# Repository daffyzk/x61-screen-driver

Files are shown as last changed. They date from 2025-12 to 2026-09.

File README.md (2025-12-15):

# x61-screen-driver

So far this is just collecting information...  

The idea is to eventually build a display driver pcb to make the screen output to HDMI/DP/eDP.  

Options for these screens on aliexpress/ebay are bulky and don't seem to be compatible with these screens either.

## Information:

There is an eDP/DP to LVDS integrated circuit from nxp, for around 5 bucks on some sites, model number PTN3460I.
the datasheet is in this repo.

There are some documents that specify some infomation on the display itself and how it comunicates

So far that's all I got, and some wikipedia articles:

[LVDS Standard](https://en.wikipedia.org/wiki/Low-voltage_differential_signaling)

## I/O 
for input, I couldn't find the original x61/x60 board-to-board connector anywhere, so I opted for this 40pin panasonic one:
https://www.digikey.com/en/products/detail/panasonic-electric-works/AXT640124/1986594
this does mean that it will required a special flex cable, but I am working on that too.

the output connector will be 20455-040E-76, standard 40pin eDP board-to-cable connector, used for displays like the BOE NE135FBM-N41
https://www.digikey.com/en/products/detail/i-pex/20455-040E-76/22108829

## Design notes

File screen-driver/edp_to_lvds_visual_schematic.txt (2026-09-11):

================================================================================
         eDP to LVDS CONVERTER - VISUAL SCHEMATIC DIAGRAM
         Framework 13 → PTN3460 → HV121P01-101 (1400x1050)
================================================================================

                         ┌─────────────────────────────────────────────────────────────────┐
                         │                                                                 │
    FRAMEWORK 13         │                      PTN3460IBS                                 │         HV121P01-101
    eDP OUTPUT           │                      (HVQFN56)                                  │         LVDS PANEL
                         │                                                                 │
  ┌──────────────┐       │  ┌─────────────────────────────────────────────────────────┐   │       ┌──────────────┐
  │              │       │  │                                                         │   │       │              │
  │  DP_LANE0_P  ├──C13──┼──┤ 4  DP0_P                                 LVSAO_P  53   ├───┼───────┤ RIN0+ (6)    │
  │  DP_LANE0_N  ├──C14──┼──┤ 5  DP0_N                                 LVSAO_N  54   ├───┼───────┤ RIN0- (5)    │
  │              │       │  │                                                         │   │       │              │
  │  DP_LANE1_P  ├──C15──┼──┤ 7  DP1_P                                 LVSBO_P  52   ├───┼───────┤ RIN1+ (9)    │
  │  DP_LANE1_N  ├──C16──┼──┤ 8  DP1_N                                 LVSBO_N  51   ├───┼───────┤ RIN1- (8)    │
  │              │       │  │                                                         │   │       │              │
  │  AUX_P       ├──C17──┼──┤ 2  AUX_P                                 LVSCO_P  48   ├───┼───────┤ RIN2+ (12)   │
  │  AUX_N       ├──C18──┼──┤ 1  AUX_N                                 LVSCO_N  49   ├───┼───────┤ RIN2- (11)   │
  │              │       │  │                                                         │   │       │              │
  │  HPD         ├───────┼──┤11  HPDRX                                LVSCKO_P  46   ├───┼───────┤ CLKIN+ (15)  │
  │              │       │  │                                         LVSCKO_N  47   ├───┼───────┤ CLKIN- (14)  │
  │              │       │  │                                                         │   │       │              │
  │  +3.3V       ├───────┼──┤    VDD3V3 (13,14,38,50)                    DDC_SCL 29   ├─┬─┼───────┤ EDID_CLK(19) │
  │  GND         ├───────┼──┤    GND (3,17,18,PAD)                       DDC_SDA 30   ├─┼─┼───────┤ EDID_DAT(20) │
  │              │       │  │                                                         │ │ │       │              │
  │  (Lane 2,3   │       │  │                                           PVCCEN  33   ├─┼─┼──NC   │ VDD (1,2)────┼──+3.3V
  │   unused)    │       │  │                                           BKLTEN  26   ├─┼─┼──────►│ LED_EN       │
  │              │       │  │                                             PWMO  28   ├─┼─┼──────►│ LED_PWM      │
  └──────────────┘       │  │                                                         │ │ │       │              │
                         │  │    CONFIG PINS:                                         │ │ │       │ GND(3,4,7,   │
       J1                │  │    ─────────────                                        │ │ │       │ 10,13,16,18) ├──GND
   40-pin eDP            │  │                                                         │ │ │       │              │
                         │  │    20 TESTMODE ◄────R5(10k)────GND                      │ │ │       └──────────────┘
                         │  │    21 CFG1 ◄────────────────────GND  (Single LVDS)      │ │ │             J2
                         │  │    22 CFG2 ◄────R6(10k)────VDD3V3    (18bpp)            │ │ │        20-pin LVDS
                         │  │    23 CFG3 ◄────────────────────GND  (2-lane eDP)       │ │ │
                         │  │    27 CFG4 ◄────R7(10k)────GND       (EDID emulation)   │ │ │
                         │  │                                                         │ │ │
                         │  │    CONTROL:                                             │ │ │
                         │  │    ────────                                             │ │ │
                         │  │     9 RST_N ◄────R8(10k)────VDD3V3                      │ │ │
                         │  │    10 PD_N  ◄────R9(10k)────VDD3V3                      │ │ │
                         │  │    56 EPS_N ◄────R10(10k)───VDD3V3   (Use int. 1.8V)    │ │ │
                         │  │    12 DEV_CFG ◄──R11(10k)───GND      (I2C addr 0x40)    │ │ │
                         │  │                                                         │ │ │
                         │  │    I2C PROGRAMMING:                                     │ │ │
                         │  │    ────────────────                                     │ │ │
                         │  │    24 MS_SDA ◄───R14(2.2k)──VDD3V3 ──────────┐          │ │ │
                         │  │    25 MS_SCL ◄───R13(2.2k)──VDD3V3 ────────┐ │          │ │ │
                         │  │                                            │ │          │ │ │
                         │  └────────────────────────────────────────────┼─┼──────────┘ │ │
                         │                                               │ │            │ │
                         └───────────────────────────────────────────────┼─┼────────────┘ │
                                                                         │ │              │
                                                                         │ │   I2C       │
                                 ┌───────────┐                           │ │  Pull-ups   │
                                 │ J3 (HDR)  │                           │ │      │      │
                                 │  1: VDD   ├───VDD3V3                  │ │      │      │
                                 │  2: SCL   ├───────────────────────────┘ │   R3(2.2k)  │
                                 │  3: SDA   ├─────────────────────────────┘      │      │
                                 │  4: GND   ├───GND                          VDD3V3    │
                                 └───────────┘                                          │
                                I2C Programming                                         │
                                    Header                                              │

================================================================================
                              POWER SUPPLY SECTION
================================================================================

                                           ┌────────────────────────────────────┐
        +3.3V_IN ──────┬───────────────────┤  VDD3V3 DISTRIBUTION               │
        (from eDP)     │                   │                                    │
                       │                   │  Pin 13 ──┬── C4(0.1µF) ── GND     │
                      C1                   │  Pin 14 ──┼── C5(0.1µF) ── GND     │
                     2.2µF                 │  Pin 38 ──┼── C6(0.1µF) ── GND     │
                       │                   │  Pin 50 ──┴── C7(0.1µF) ── GND     │
                      GND                  │                                    │
                                           └────────────────────────────────────┘

                                           ┌────────────────────────────────────┐
                                           │  1.8V REGULATOR OUTPUT (Pin 19)    │
                                           │                                    │
        Pin 19 (VDD1V8_REG) ───┬───────────┤  ──┬── C8(4.7µF) ── GND            │
                               │           │    │                               │
                              L2           │    └── C9(0.1µF) ── GND            │
                             (FB)          │                                    │
                               │           │  VDD1V8 DISTRIBUTION:              │
                               └─ VDD1V8 ──┤                                    │
                                           │  Pin 6  ──┬── C10(2.2µF)── GND     │
                                           │           └── C11(0.1µF)── GND     │
                                           │  Pin 45 ──── C12(0.1µF)── GND      │
                                           │                                    │
                                           └────────────────────────────────────┘

================================================================================
                            LVDS SIGNAL MAPPING
================================================================================

    PTN3460 Output          Signal Content              Panel Input
    ──────────────          ──────────────              ───────────
    LVSAO_P/N (53/54)  →    R0-R5, G0 (Ch A)       →   RIN0+/- (6/5)
    LVSBO_P/N (52/51)  →    G1-G5, B0, B1 (Ch B)  →   RIN1+/- (9/8)
    LVSCO_P/N (48/49)  →    B2-B5, HS, VS, DE (Ch C) → RIN2+/- (12/11)
    LVSCKO_P/N (46/47) →    Pixel Clock            →   CLKIN+/- (15/14)

    Note: Using "Odd" bus outputs only (single channel mode)
          "Even" bus outputs (pins 31-42) are unused
          Channel D outputs (pins 43/44) unused in 18bpp mode

================================================================================
                         CONFIGURATION SUMMARY
================================================================================

    ┌────────────┬─────────┬───────────────────────────────────────┐
    │ Pin        │ Setting │ Function                              │
    ├────────────┼─────────┼───────────────────────────────────────┤
    │ TESTMODE   │ LOW     │ Enable CFG pins (not JTAG)            │
    │ CFG1       │ LOW     │ Single LVDS bus                       │
    │ CFG2       │ HIGH    │ 18bpp (6-bit per color)               │
    │ CFG3       │ LOW     │ 2-lane eDP input                      │
    │ CFG4       │ LOW     │ EDID emulation from internal flash    │
    │ EPS_N      │ HIGH    │ Use internal 1.8V regulator           │
    │ RST_N      │ HIGH    │ Normal operation (not reset)          │
    │ PD_N       │ HIGH    │ Normal operation (not power down)     │
    │ DEV_CFG    │ LOW     │ I2C slave address = 0x40              │
    └────────────┴─────────┴───────────────────────────────────────┘

================================================================================
                            TYPICAL VALUES
================================================================================

    Power consumption:     ~300-450mW (active, single supply)
    Input voltage:         3.3V ± 10%
    LVDS output swing:     300mV differential (default)
    Pixel clock:           84.8 MHz (1400x1050 @ 60Hz)
    eDP link rate:         2.7 Gbps (HBR) or 1.62 Gbps (RBR)

================================================================================
                        ESTIMATED BOARD SIZE
================================================================================

                    ┌──────────────────────────────────────┐
                    │                                      │
                    │    ┌──────┐                          │
                    │    │      │                          │
            J1 ═════╡    │ U1   │    ○ ○ ○ ○  J3           │
           eDP      │    │      │    (I2C)                 │
                    │    └──────┘                          │
                    │         ▪▪▪▪▪▪▪▪  (caps)             │
                    │                                      ╞═════ J2
                    │    R R R R R R  (config)             │      LVDS
                    │                                      │
                    └──────────────────────────────────────┘
                    
                    Approximate size: 35mm x 25mm (4-layer)

================================================================================
                                NOTES
================================================================================

1. All capacitors: X5R or X7R ceramic, 0402 or 0603 package
2. All resistors: 0402 or 0603 package, 1% tolerance
3. Ferrite beads: High frequency type, e.g., BLM18AG601
4. Use 4-layer PCB with solid ground plane
5. Match differential pair lengths within 5 mils
6. Keep eDP and LVDS traces short and direct
7. Ensure good thermal connection for center pad
8. AC coupling caps (C13-C18) should be close to PTN3460

================================================================================

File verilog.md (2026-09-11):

First, start by coding a simpler version of this project on the tang nano 9k.

I could make an HDMI -> LVDS(screen) driver, maybe not at full resolution but at least something, learn some verilog and try stuff out.

Then, I get an FPGA with actual high throughput transcievers, like the Tang Mega 138K or 60K

Develop the real driver code on that, then get a GW5AT-LV15MG132C1/I0 for the final PCB.

GW5AT-LV15 = Arora V 15K Logic Elements with Transceivers.
MG132 = The 8x8mm Micro-BGA package.
C1/I0 = The temperature grade (Commercial/Industrial) and speed grade.

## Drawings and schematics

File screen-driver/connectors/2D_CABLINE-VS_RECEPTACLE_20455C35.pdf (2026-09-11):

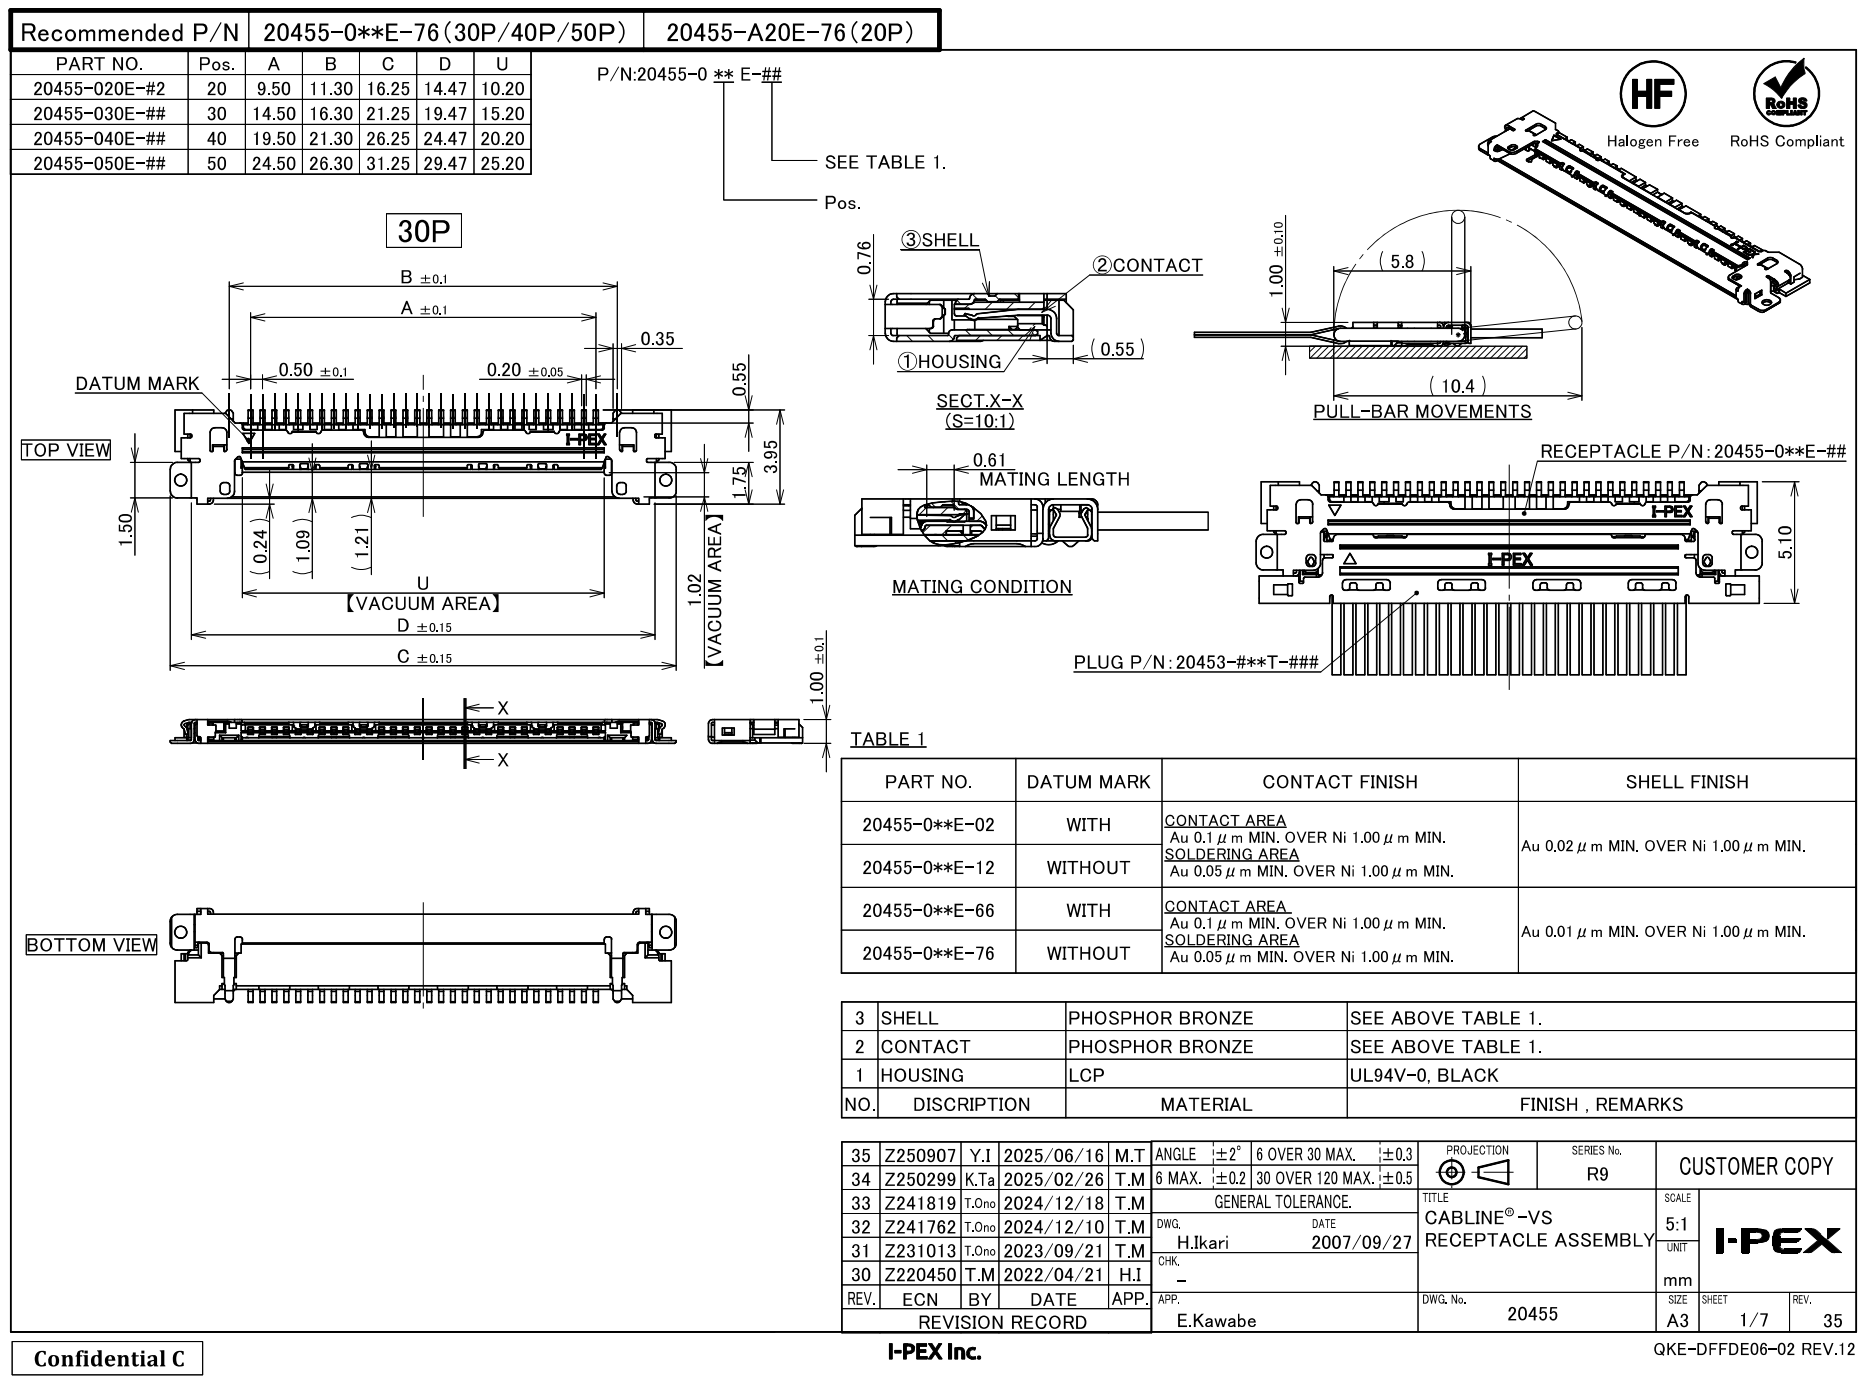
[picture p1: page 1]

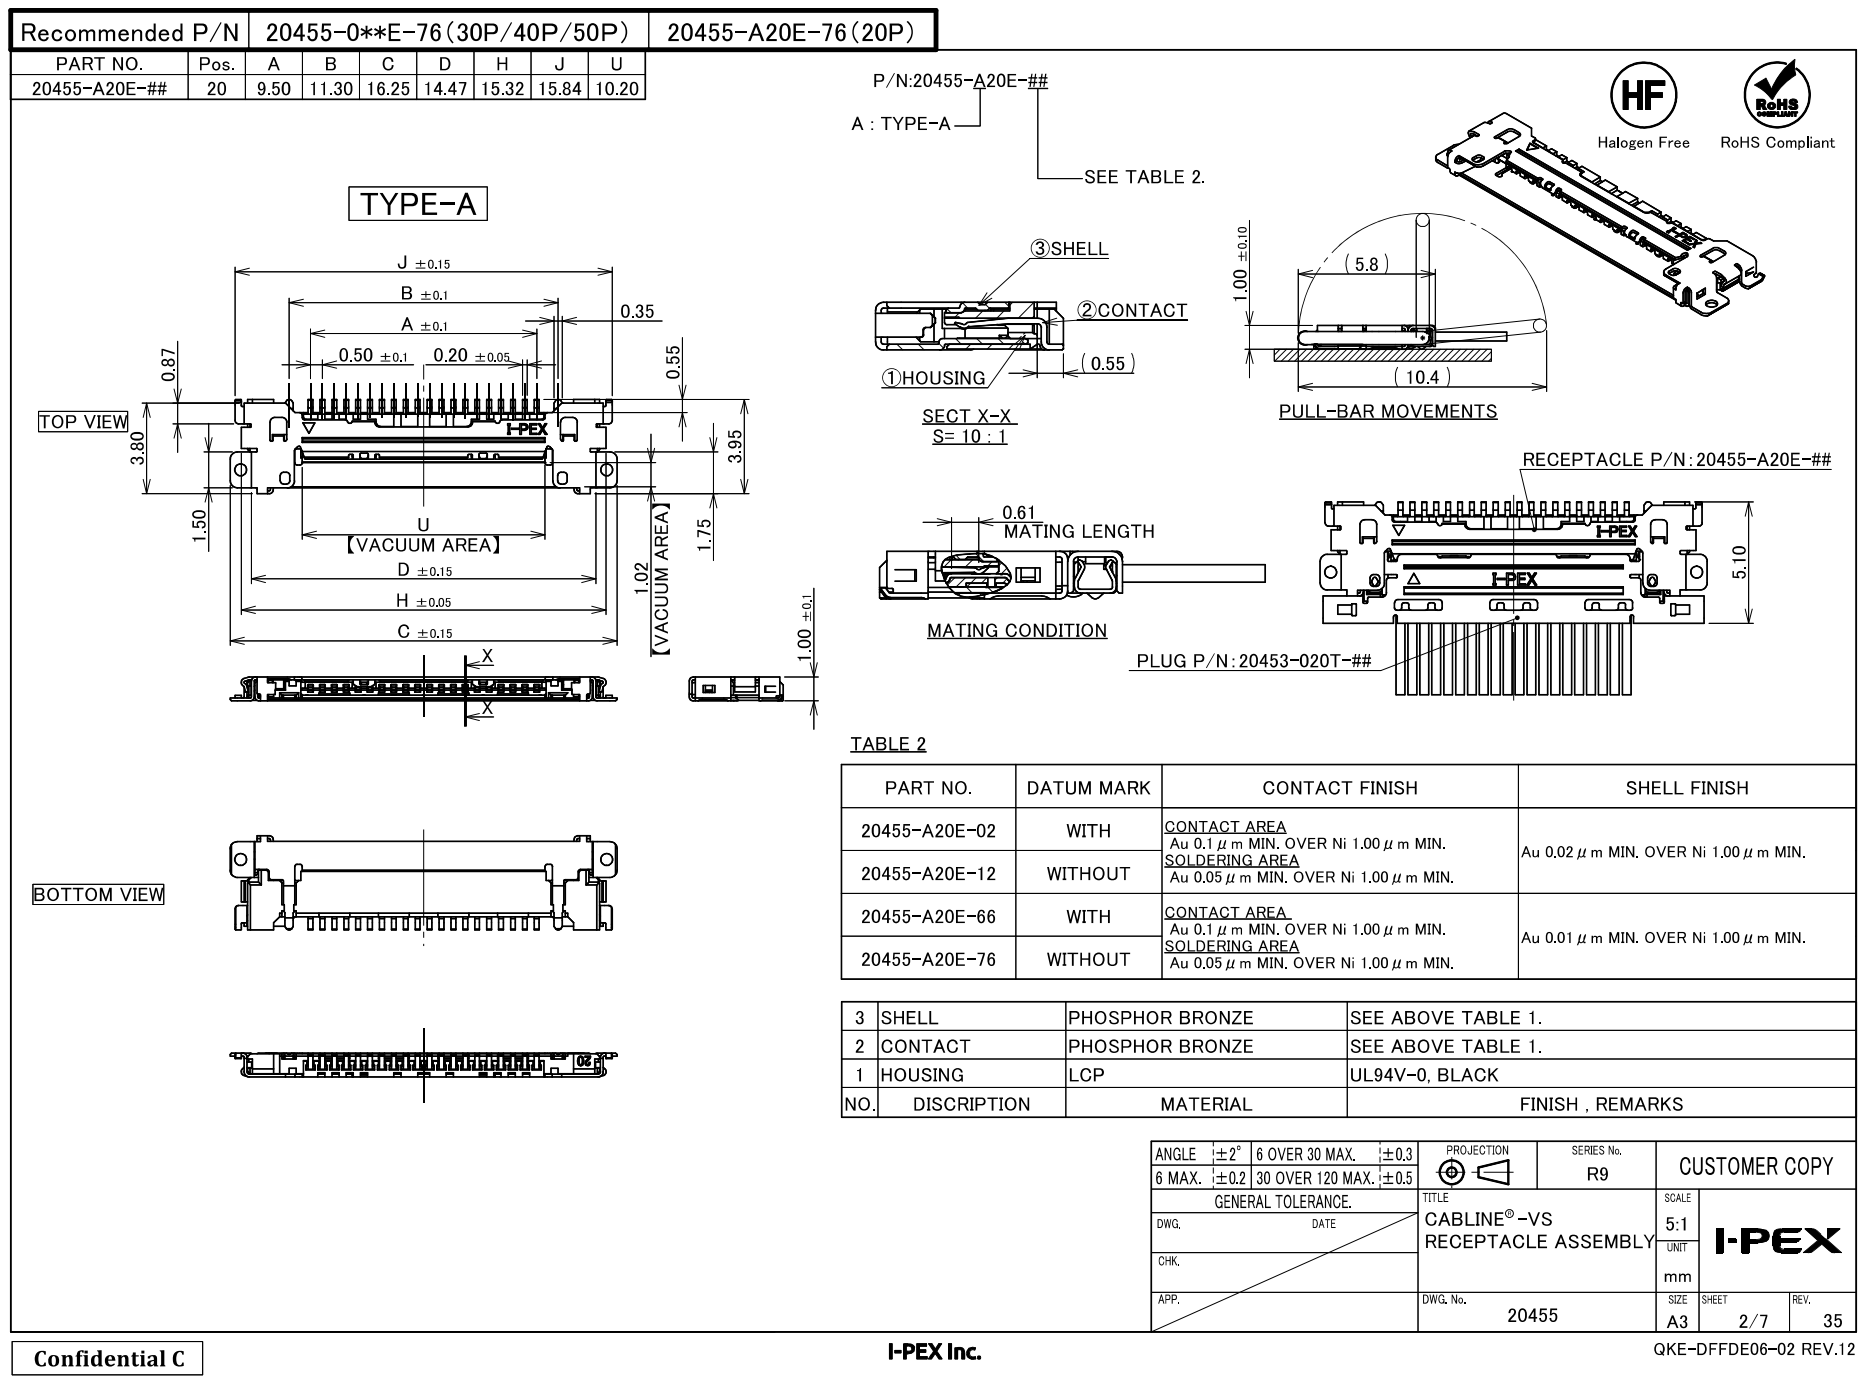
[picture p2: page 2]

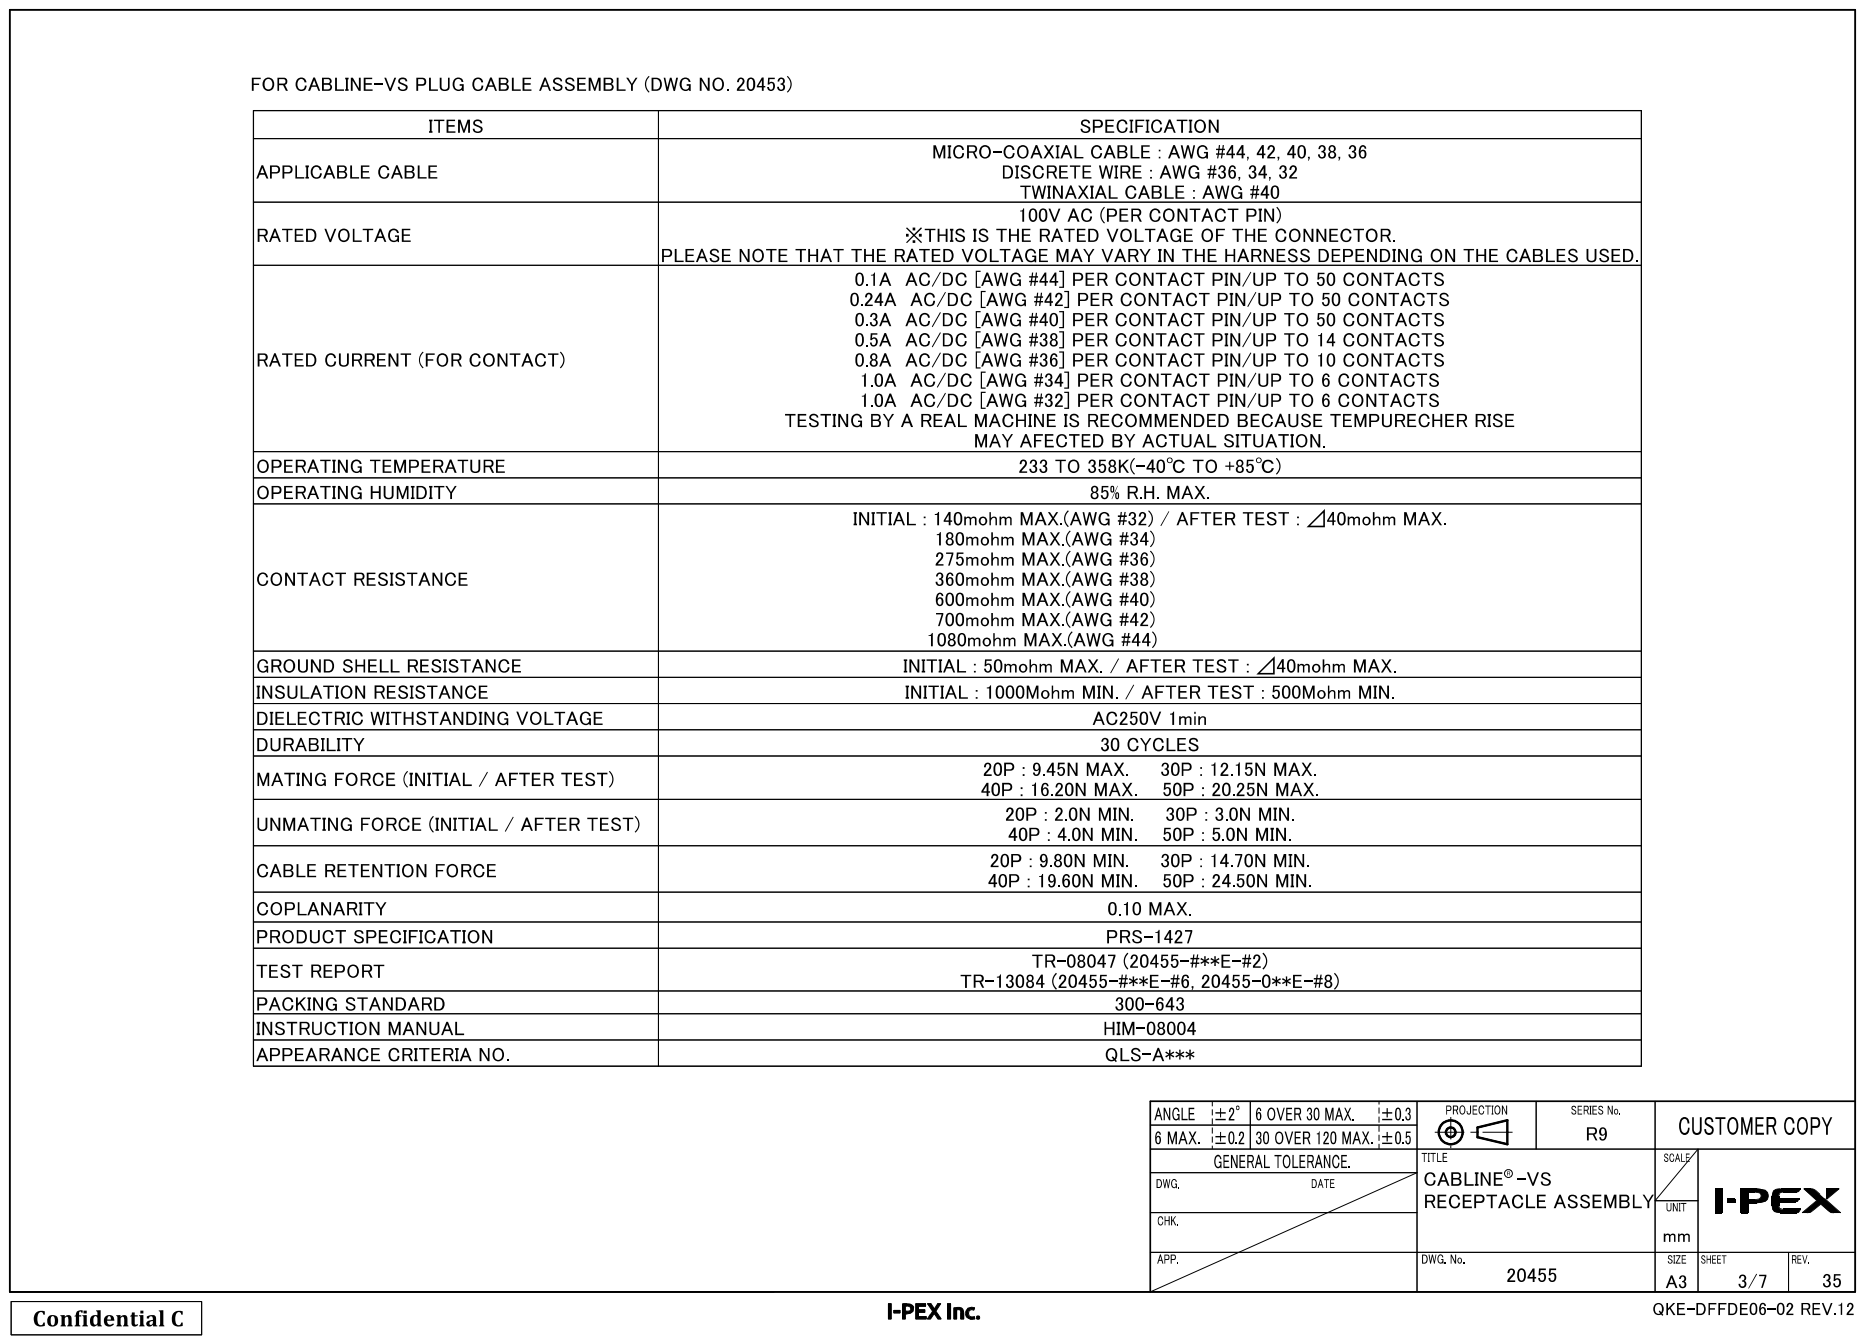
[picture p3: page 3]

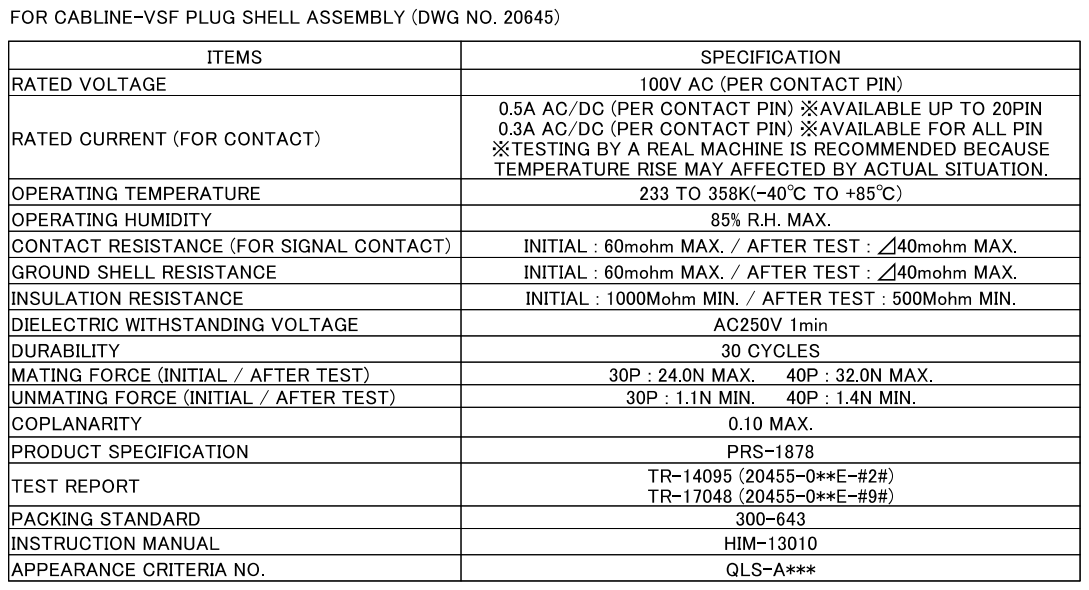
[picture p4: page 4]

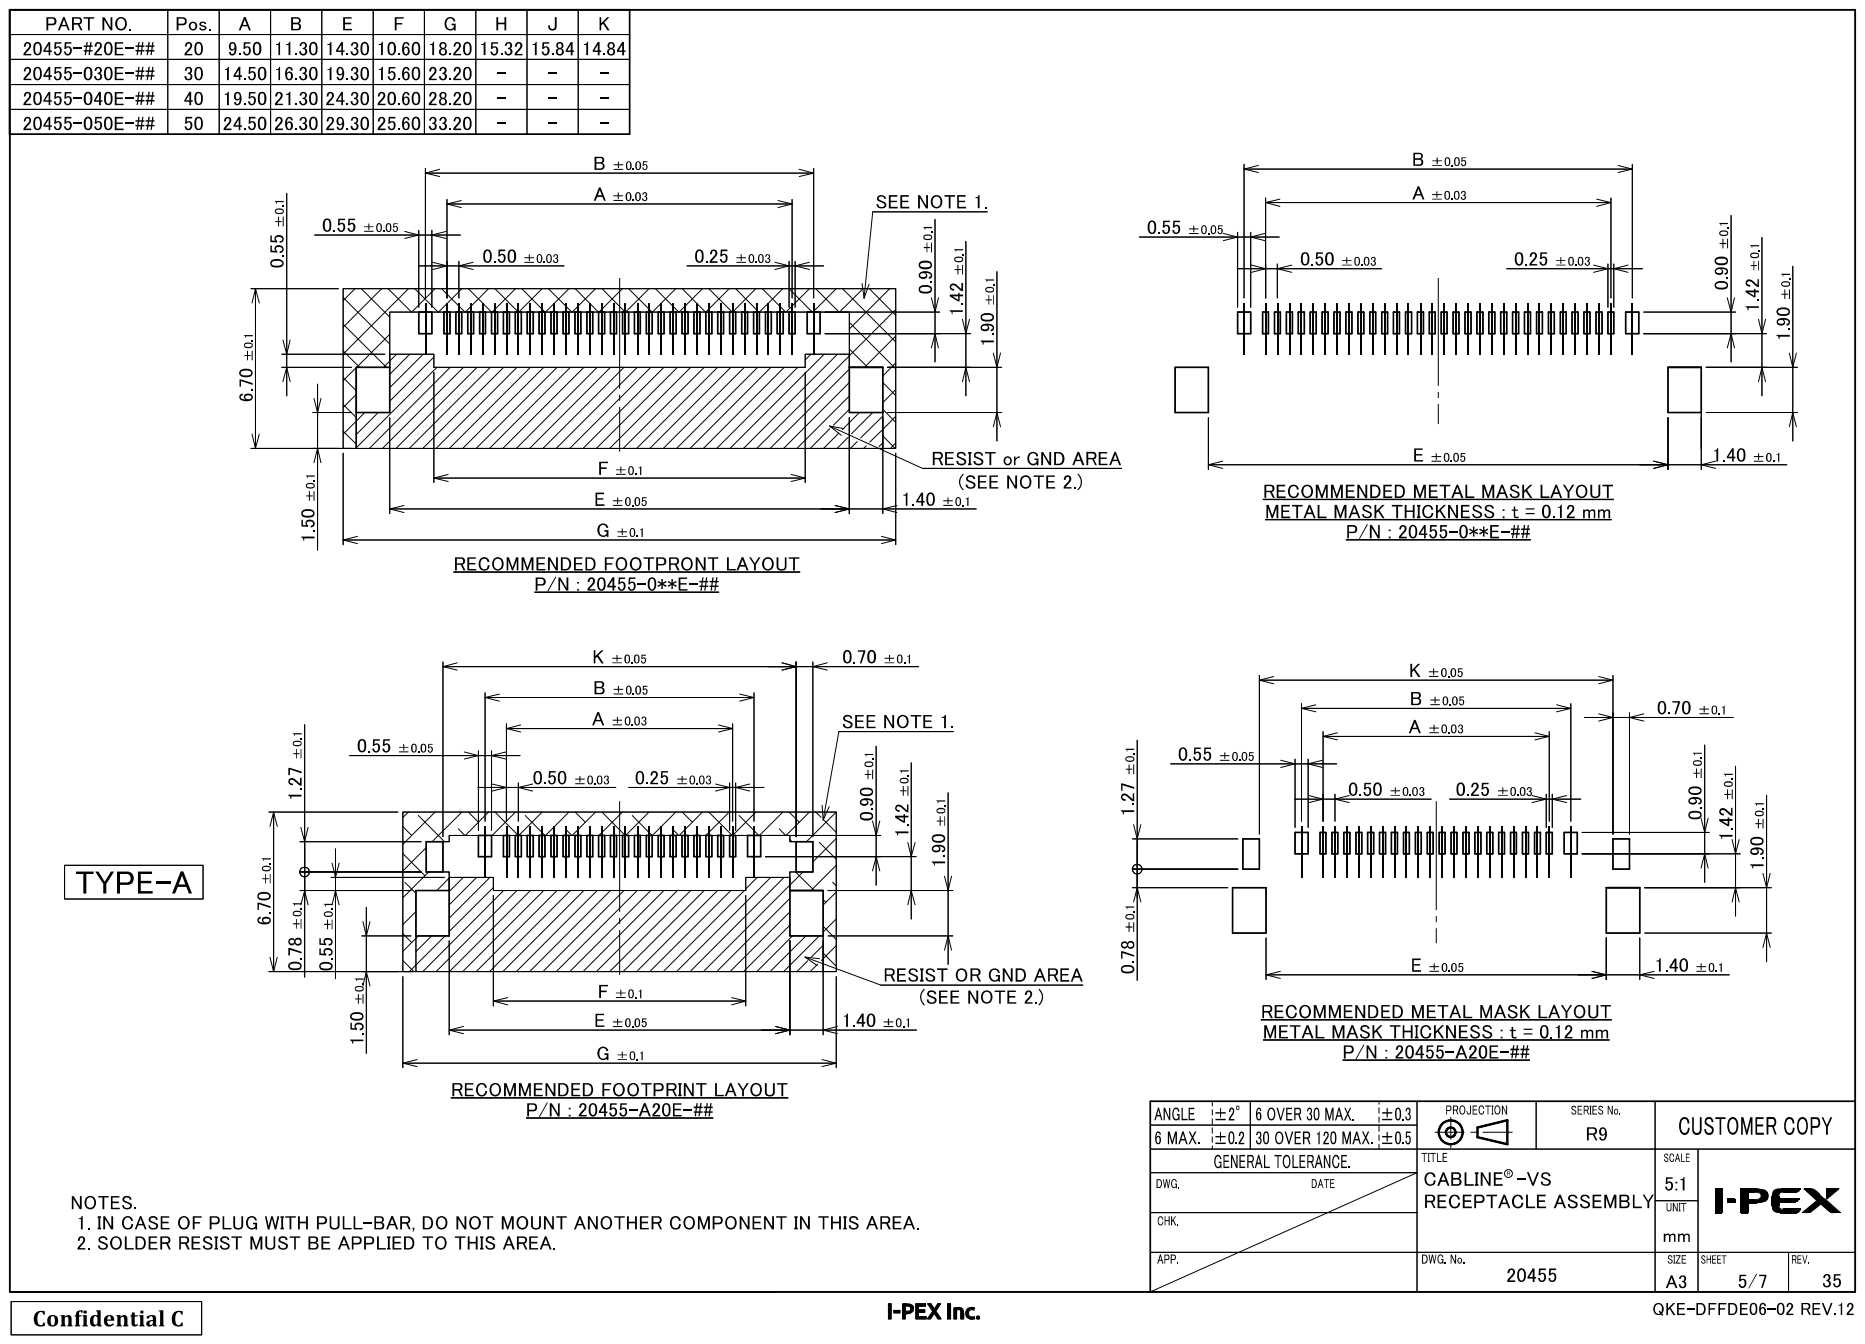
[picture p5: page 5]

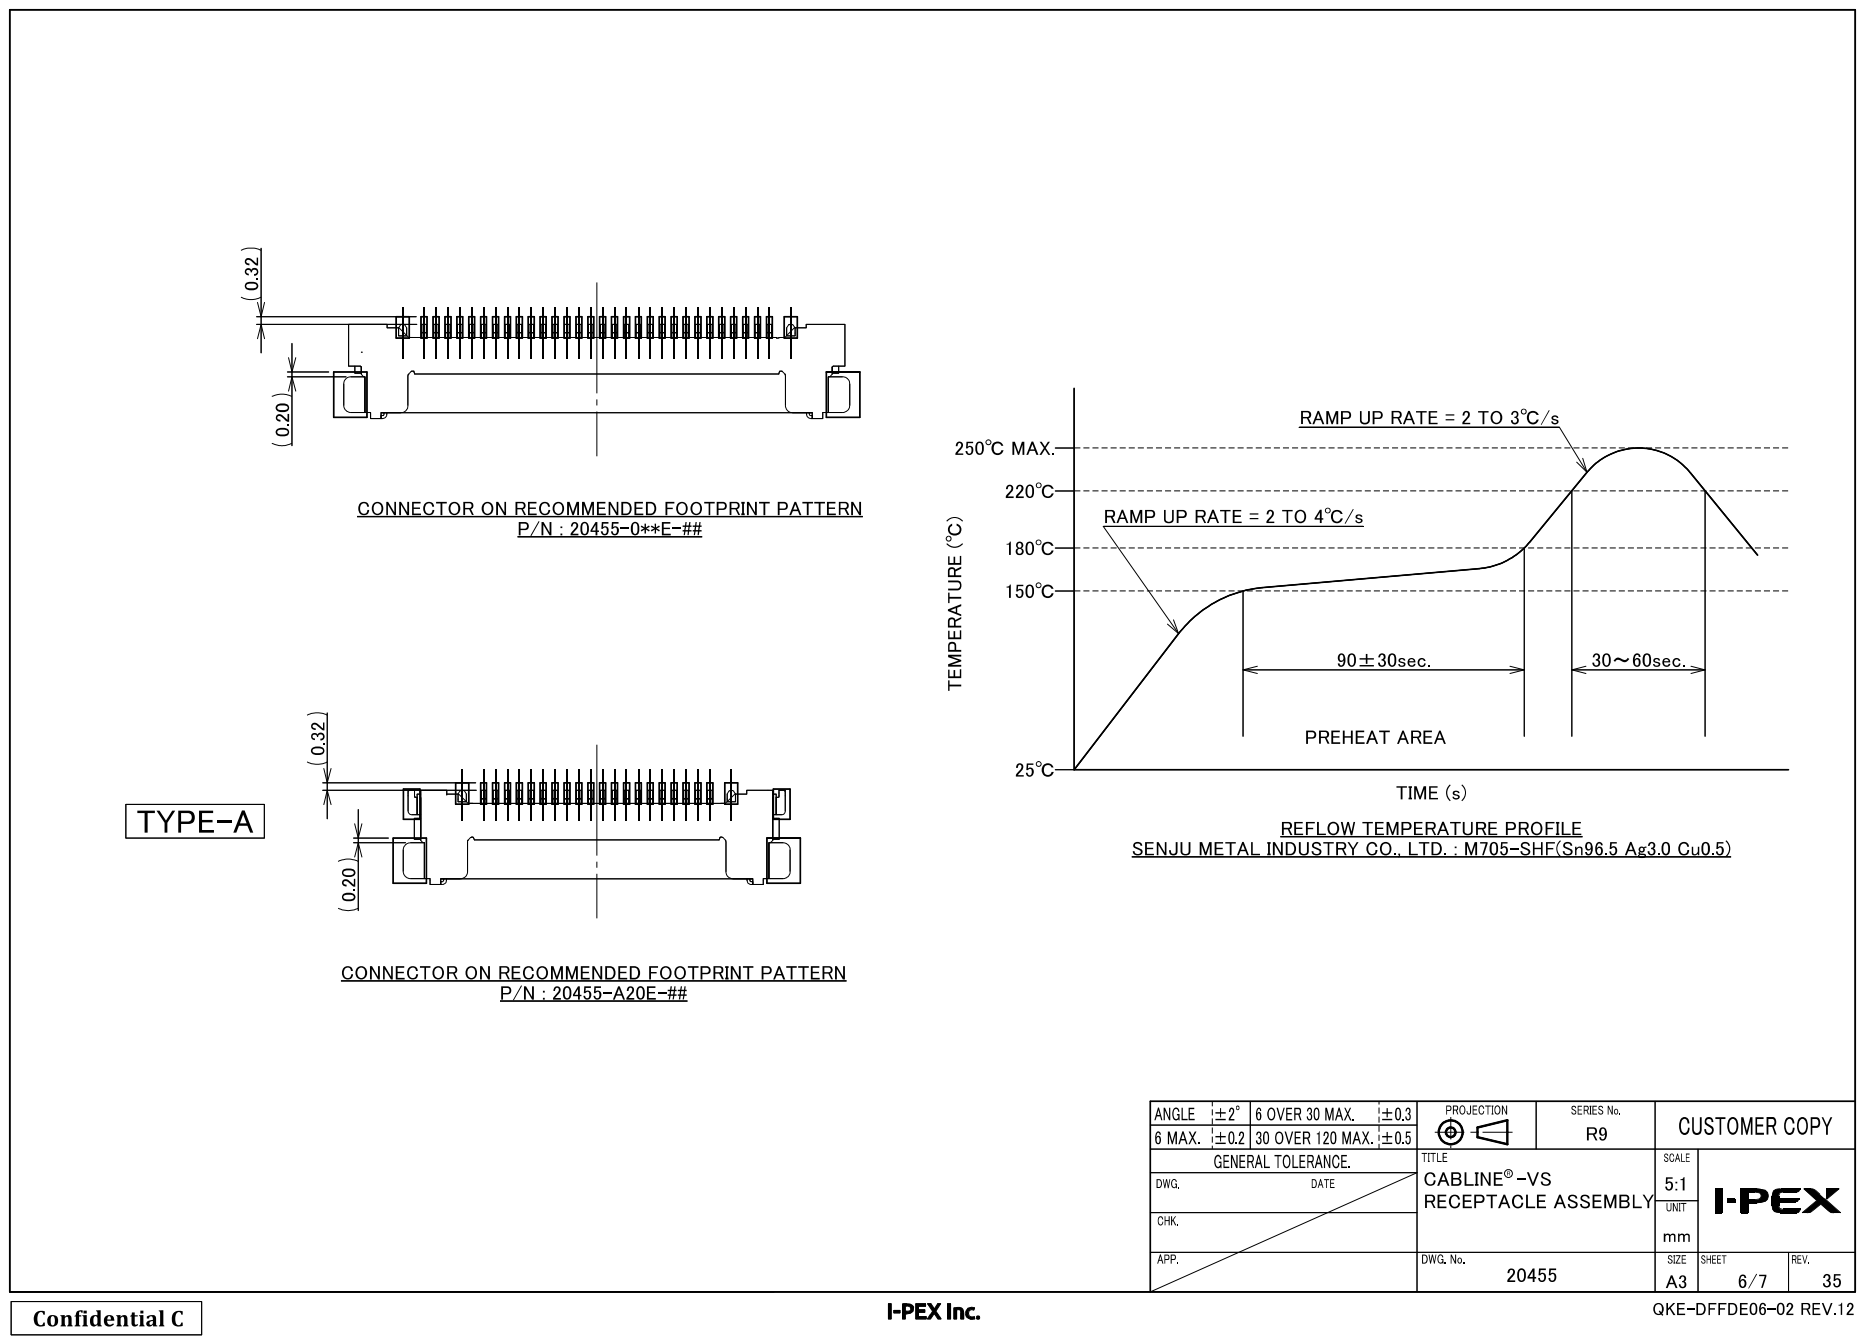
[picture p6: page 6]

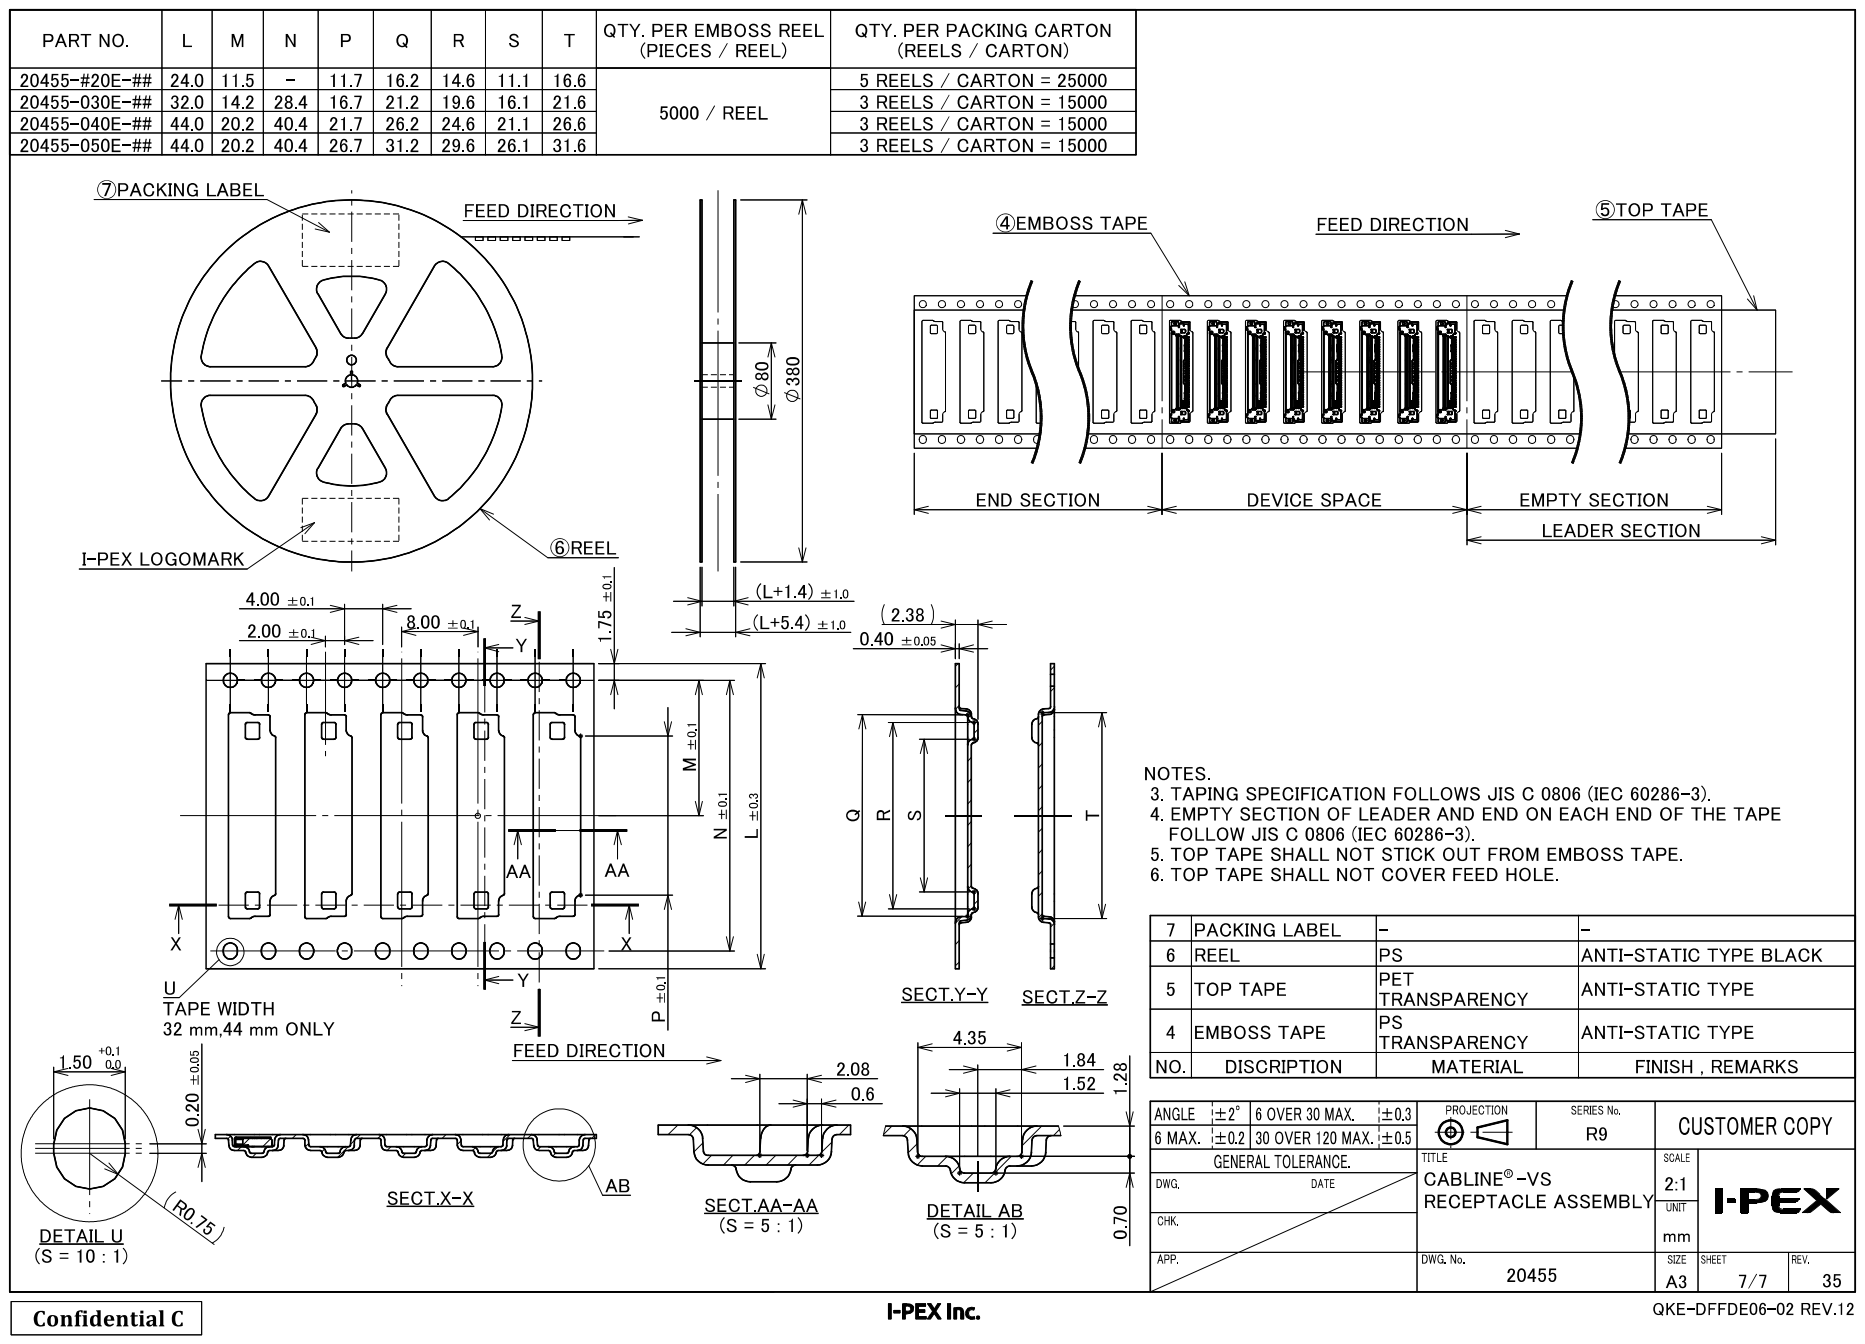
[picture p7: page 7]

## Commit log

2025-11-21 added docs
    [screen-driver.kicad_pcb, screen-driver.kicad_sch]
2025-12-15 connectors maybe
2025-12-18 added connector footprints and symbols!
    [screen-driver.kicad_sch]
2025-12-20 footprints + had to change the eDP to LVDS IC for a 4 channel one
    [screen-driver.kicad_sch]
2026-09-11 added edp-to-lvds schematics
